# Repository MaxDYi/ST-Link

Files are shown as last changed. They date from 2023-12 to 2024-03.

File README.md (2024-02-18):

# ST-Link V2.1

# 0 简介

ST-Link V2.1使用STM32F103C8T6/CBT6作为主控，二者可以Pin to Pin替换，CBT6的容量更大，可以满足后续固件升级需要，同时该调试器板载虚拟串口。

ST-Link V2.1可以通过HDR 2.54 2x5P接口进行SWD或者JTAG调试。同时附带一个8P的FPC0.5mm接口，可以在板面积紧张时使用该接口进行调试，但该接口仅支持SWD调试。



调试器下方的HDR 1.27 4P接口为烧录固件的接口，无需焊接。

调试器中板载一颗红色ST-LINK COM LED，该LED状态指示如下：

| LED状态 | ST-LINK运行状态 |
| --- | --- |
| LED呈红色闪烁（第一次） | 正在与PC进行第一个USB枚举 |
| LED为红色 | PC与ST-LINK之间的通信已建立（枚举结束） |
| LED呈红色闪烁 | 正在目标和PC之间交换数据 |

调试器所有接口均为3.3V电平，USB输入5V使用6V100mA的自恢复保险丝进行保护。板载3.3V使用XC6206，也带有6V100mA的自恢复保险丝，共可以输出100mA。

# 1 原理图

ST-Link-V2.1-SCH_page-0001

# 2 PCB





PCB使用双层板设计，面积4.0x1.5cm，仅正面布有元器件。

PCB使用1.6板厚，若使用2.0板厚时HDR 2x5P接口卡合会更紧，但工程费会更贵。

# 3 物料清单

| Comment | Description | Designator | Footprint | LibRef | Quantity |
| --- | --- | --- | --- | --- | --- |
| 20pF | 贴片电容/MLCC电容 | C1, C2 | C0402_M | C | 2 |
| 100nF | 贴片电容/MLCC电容 | C3, C4, C5, C6, C7,  C8, C9 | C0402_M | C | 7 |
| 1uF | 贴片电容/MLCC电容 | C10, C11 | C0402_M | C | 2 |
| 1N5819 | 肖特基二极管 | D1 | SOD-323 | 1N5819 | 1 |
| 6V 100mA | 方形保险丝 | F1, F2 | F0805 | FUSE-8.5*4.0*8.0 | 2 |
| HDR-1X5 | 5P接插件 | JP1, JP2 | HDR2.54-WS-5P | Header 5 | 2 |
| HDR-1X4 | 4P接插件 | JP3 | HDR1.27-LI-4P | Header 4 | 1 |
| CON-8P | 8P连接器 | JP4 | FPC0.5-WT-8P-双侧触点 | Header 8 | 1 |
| RED | 贴片LED | LED1, LED5 | LED0603_R | LED | 2 |
| GREEN | 贴片LED | LED3 | LED0603_G | LED | 1 |
| BLUE | 贴片LED | LED4 | LED0603_B | LED | 1 |
| S9013 | 低频放大-NPN型 | Q1 | SOT23-3N | 9013-SMD | 1 |
| 10K | 贴片电阻 | R1, R2, R3, R12, R16 | R0402_M | R | 5 |
| 4K7 | 贴片电阻 | R4, R10, R11 | R0402_M | R | 3 |
| 100R | 贴片电阻 | R5, R13 | R0402_M | R | 2 |
| 1K | 贴片电阻 | R6, R18, R19, R20 | R0402_M | R | 4 |
| 100K | 贴片电阻 | R9 | R0402_M | R | 1 |
| 10R | 贴片电阻 | R14, R15 | R0402_M | R | 2 |
| 1K5 | 贴片电阻 | R17 | R0402_M | R | 1 |
| 5.1K | 贴片电阻 | R21, R22 | R0402_M | R | 2 |
| STM32F103CBT6 | STM32 ARM-based  32-bit MCU | U1 | LQFP48_N | STM32F103CBT6 | 1 |
| XC6206P332MR | LDO 3.3V/0.25A | U2 | SOT23-3N | XC6206P332MR | 1 |
| TYPE-C 2.0  -16P | USB2.0_Type-C_16Pin母座 | USBC1 | USB-C-SMD_16P | USB2.0_Type-C_16Pin | 1 |
| 8MHz | 2脚无源晶振(谐振器） | X1 | OSC-5032-2P | XTAL-2P | 1 |

# 4 固件烧录

固件烧录时需要先使用一个ST-LINK进行固件烧录，固件有**STLinkV2.J16.S4.bin**与**STLinkV2.J28.M18.bin**（推荐）两版。

使用[STM32CubeProgrammer](https://www.st.com/zh/development-tools/stm32cubeprog.html)进行烧录，如提示**Failed to read memory**，表示目前芯片有写保护，在配置寄存器中解除保护后再烧写固件即可。

烧录完成后使用USB连接调试器，使用[STSW-LINK007](https://www.st.com/zh/development-tools/stsw-link007.html)工具进行固件升级，升级类型可以选择。

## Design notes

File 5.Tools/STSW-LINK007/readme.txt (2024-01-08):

STLink firmware upgrade applications

1. In folder Windows:

   Contains the application in its "historical" form: executable dedicated to Windows + dll.
   With all most recent firmwares (V1J13S3 for ST-Link/V1 boards, V2J43S7 for ST-Link/V2 boards,
   V2J43M28 for ST-Link/V2-1 boards, V3J13M4 for STLINK-V3 boards, V4J3B1P4 for STLINK-V3PWR)

2. In folder AllPlatforms:

   Contains a new GUI based on Java, with native ST-Link libraries for running on Windows 32 bits,
   Windows 64bits, Linux 32bits, Linux 64bits and MacOS 64bits.
   
   The application requires the Java Runtime Environment 7u51 (or more recent) being installed.
   In platforms without .jar file extension association, the application can be launch by the command
   "java -jar STLinkUpgrade.jar".

   On Linux, the application relies on libusb-1.0, which must be installed separately. For
   instance on Ubuntu, through the command "sudo apt-get install libusb-1.0".

   On Linux, users must be granted with rights for accessing the ST-Link USB devices. To do
   that, it might be necessary to add rules into /etc/udev/rules.d. This can be achieved by
   running one of the package provided into the subdirectory StlinkRulesFilesForLinux.

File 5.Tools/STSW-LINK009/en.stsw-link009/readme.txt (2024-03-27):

Digitally signed USB driver for ST-Link/V2 on Windows7, Windows8 and Windows10,
32 and 64 bits.

To install the driver, run stlink_winusb_install.bat in administrator mode, before
connecting any ST-Link to the PC.

In case of issue, it's also possible to run (as administrator):
 - dpinst_x86.exe on 32 bits machines
 - dpinst_amd64.exe on 64 bits machines

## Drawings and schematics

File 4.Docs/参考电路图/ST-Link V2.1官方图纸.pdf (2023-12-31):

## SWD

## SWD

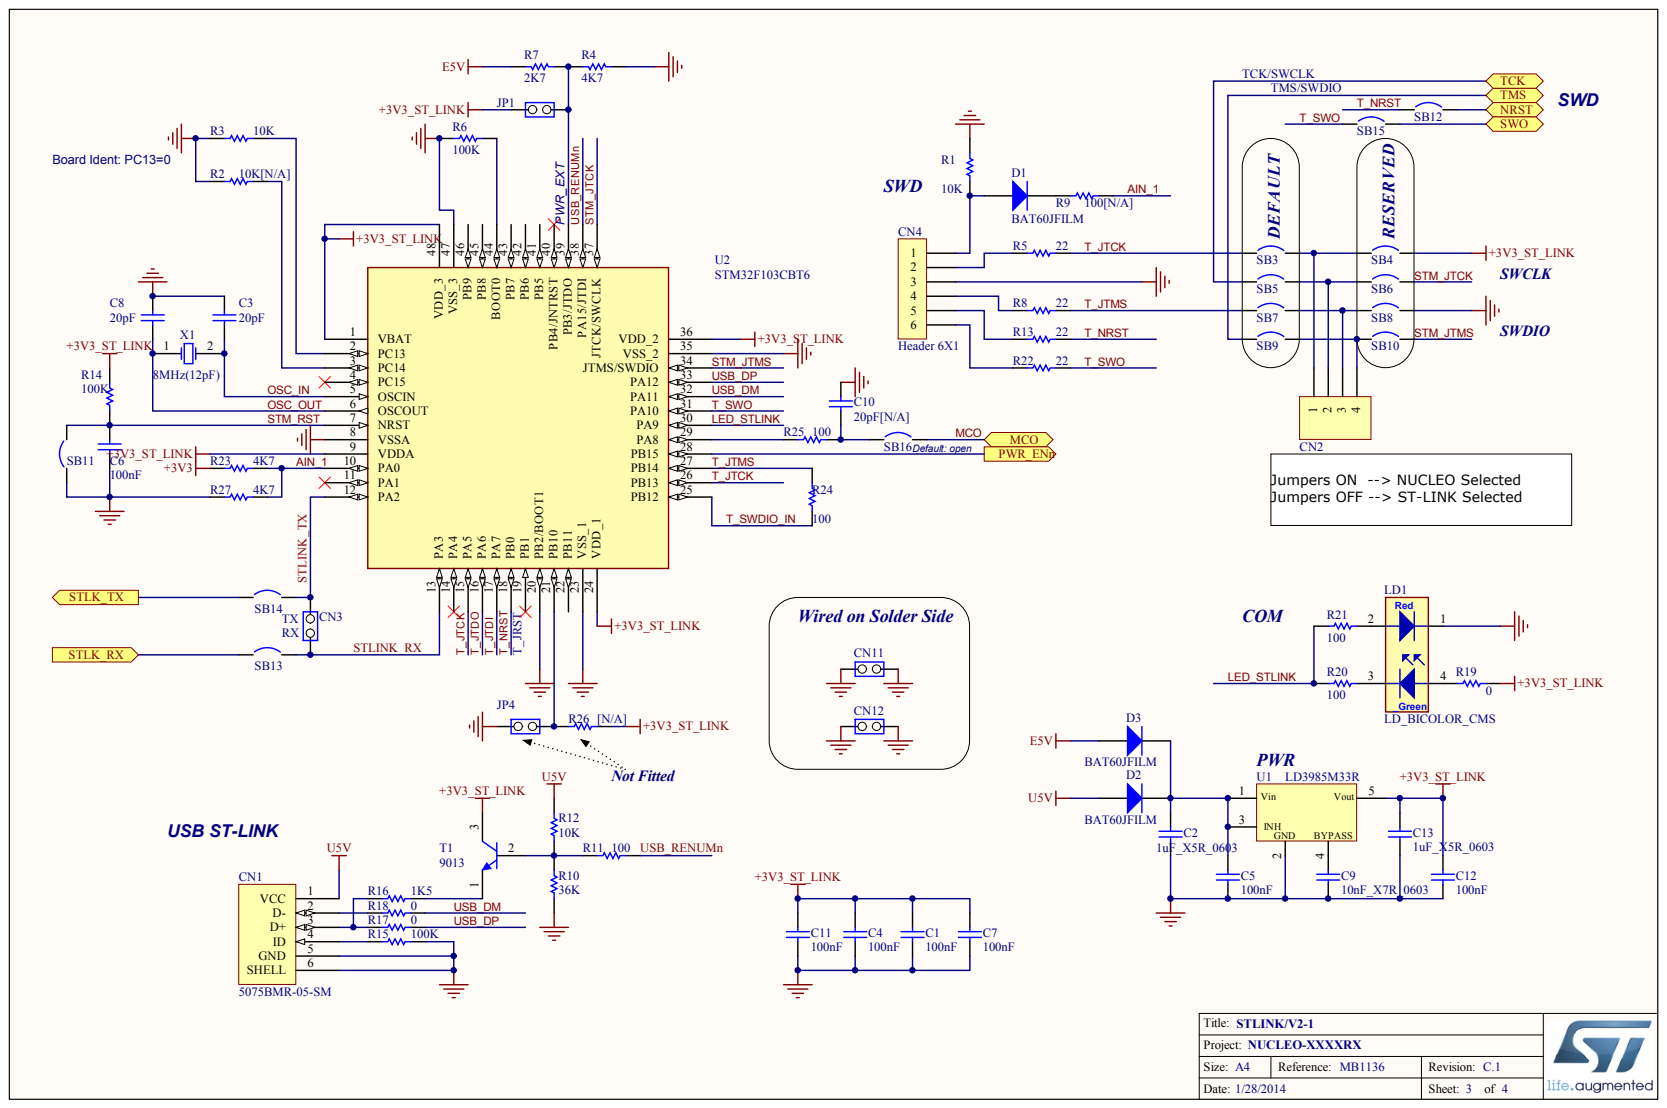
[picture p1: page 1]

Jumpers ON --> NUCLEO Selected
Jumpers OFF --> ST-LINK Selected

Wired on Solder Side

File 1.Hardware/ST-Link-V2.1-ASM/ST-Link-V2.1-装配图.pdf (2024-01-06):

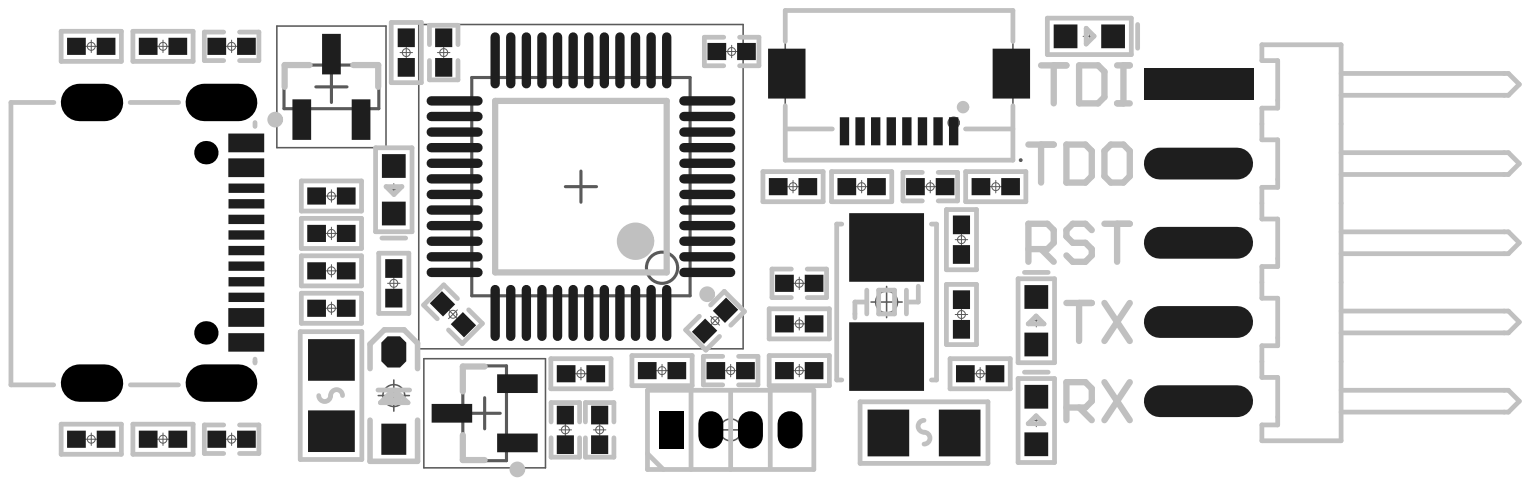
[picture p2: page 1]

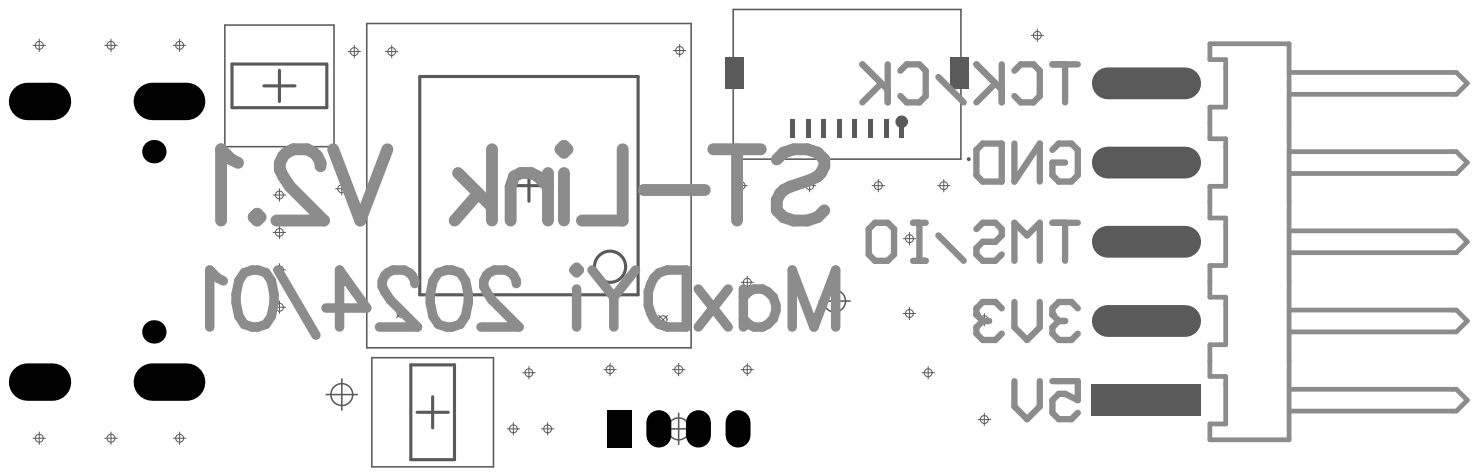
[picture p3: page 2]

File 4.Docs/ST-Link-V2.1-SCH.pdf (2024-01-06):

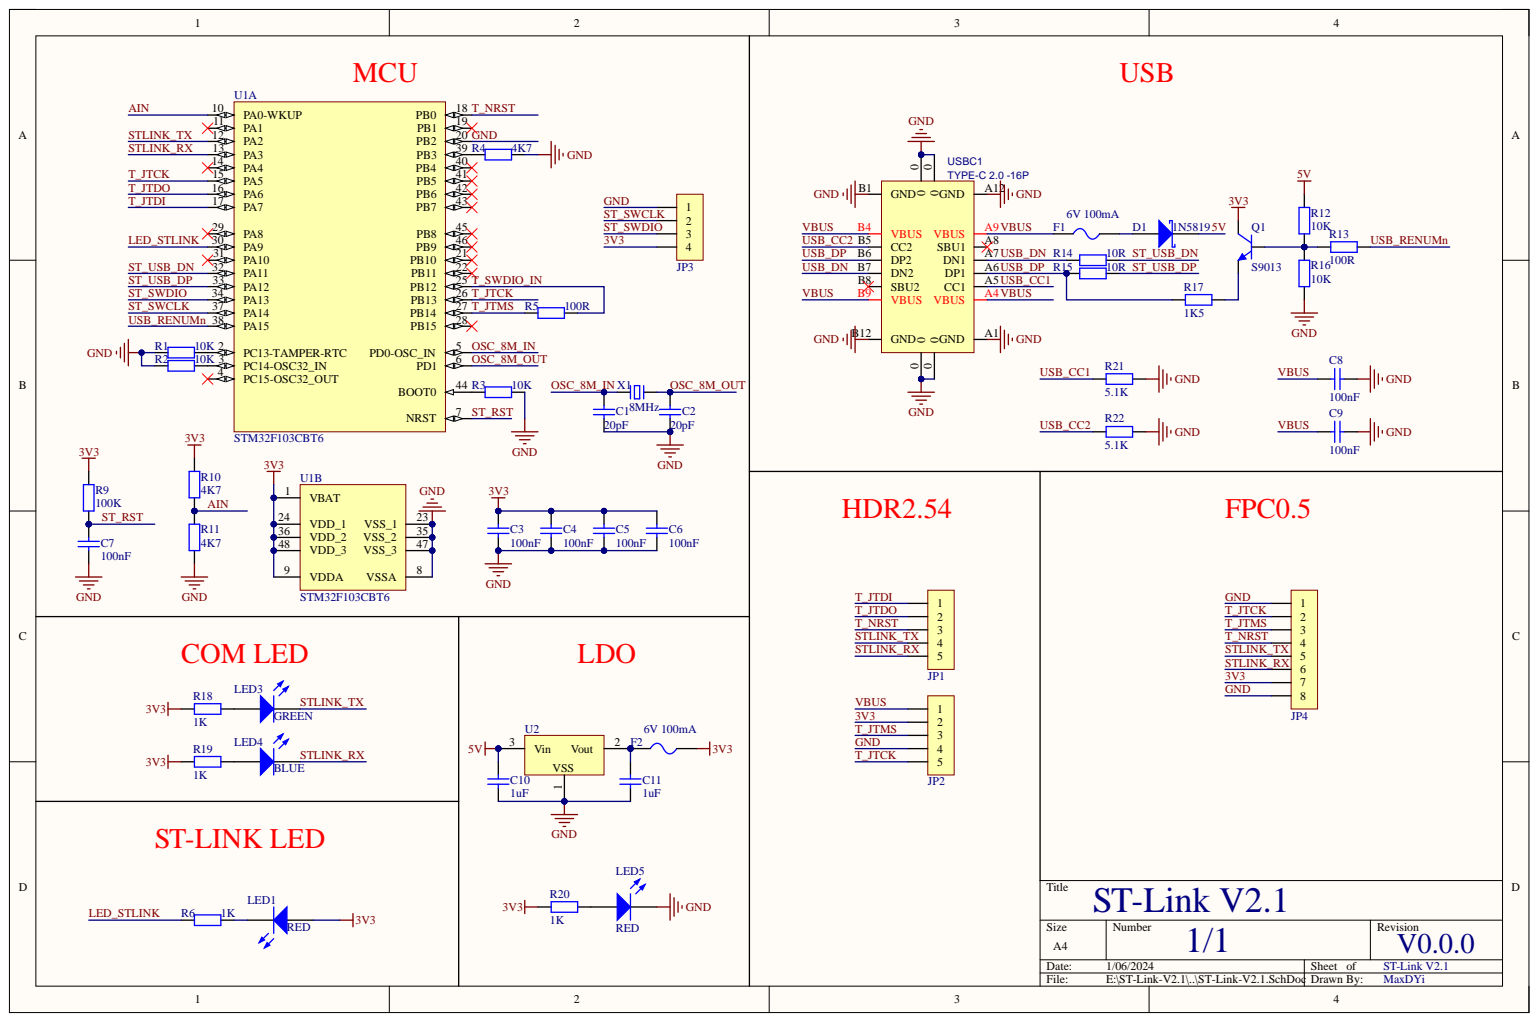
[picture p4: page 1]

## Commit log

2023-12-31 ST-Link工程
    [ST-LINK.PcbDoc, ST-LINK.SchDoc, ST-Link.PrjPcb]
2023-12-31 新建pcb工程
    [ST-Link-V2.1.PcbDoc, ST-Link-V2.1.PrjPcb, ST-Link-V2.1.SchDoc]
2023-12-31 除3V3与GND连接完成
    [ST-Link-V2.1.PrjPcb, ST-Link-V2.1.SchDoc]
2023-12-31 LDO手册
2023-12-31 设计参考电路图
2023-12-31 ST-LINK相关文件
2023-12-31 新增README
2023-12-31 旧版固件
2024-01-01 DRC检查通过
    [ST-Link-V2.1-BOM.xlsx, ST-Link-V2.1.PrjPcb, ST-Link-V2.1.SchDoc]
2024-01-06 第一版电路图
2024-01-08 ST-LINK固件升级工具
2024-01-12 使用说明
2024-01-12 ST烧录工具
2024-01-22 添加相关库
    [ST-Link-V2.1.PcbLib, ST-Link-V2.1.PrjPcb, ST-Link-V2.1.SchLib]
2024-01-25 修改烧写流程
2024-02-18 修改部分一级标题
2024-03-27 添加ST-Link驱动
